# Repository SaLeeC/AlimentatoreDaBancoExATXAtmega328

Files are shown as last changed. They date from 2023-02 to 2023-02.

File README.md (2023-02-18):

# PowerSupplyFromATXPowerUnit

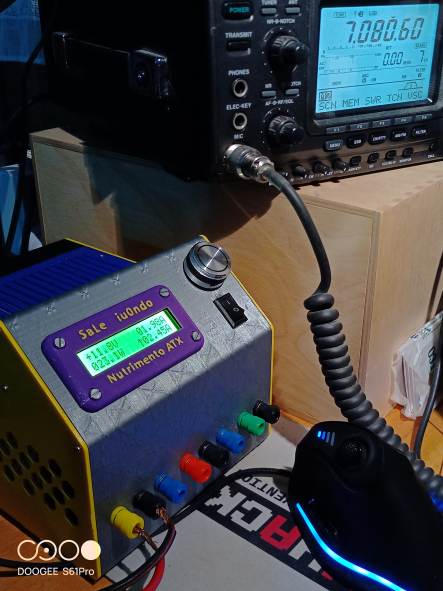
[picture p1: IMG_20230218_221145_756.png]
Immagine

          
Desk power supply made using an ATX power module salvaged from an old computer.

Alimentatore da banco realizzato utilizzando un modulo di alimentazione ATX recuperato da un vecchio computer.

# Firmware
The firmware was developed with PlatformIO.
A modified version of the library developed by Adafruit was used to interface the INA219 chip.
library update request to its developer is in progress.
At the moment, to compile without errors, you must do the following:
1) Copy the project folder to your computer
2) open the "lib\Adafruit INA219-CopiaDiSecurità" folder inside the project folder and copy its contents
3) open the ".pio\libdeps\uno\Adafruit INA219" folder and paste the copied files into it, authorizing the replacement of all files
This sequence does NOT affect other projects in your folders.
Until you upgrade the libraries this sequence will no longer be needed. 

Il firmware è stato con sviluppato con PlatformIO.
Per l'interfacciamento del chip INA219 è stata utilizzata una versione modificata della libreria sviluppata da Adafruit.
è in corso la richiesta di aggiornamento della libreria al suo sviluppatore.
Al momneto per eseguire la compilazione senza errori si deve effettuare le seguenti operazioni:
1) Copiare la cartella di progetto sul vostro computer
2) aprire la cartella "lib\Adafruit INA219-CopiaDiSicurezza" all'interno della cartella di progetto e copiarne il contenuto
3) aprire la cartella ".pio\libdeps\uno\Adafruit INA219" e incollarvi dentro i file copiati autorizzando la sostituzione di tutti i file
Questa sequenza NON influenza gli altri progetti presenti nelle vostre cartelle.
Fino a quando non eseguirete l'aggiornamento delle librerie questa sequenza non sarà più necessaria.

# Box
https://grabcad.com/library/box-for-atx-power-supply-ex-pc-1

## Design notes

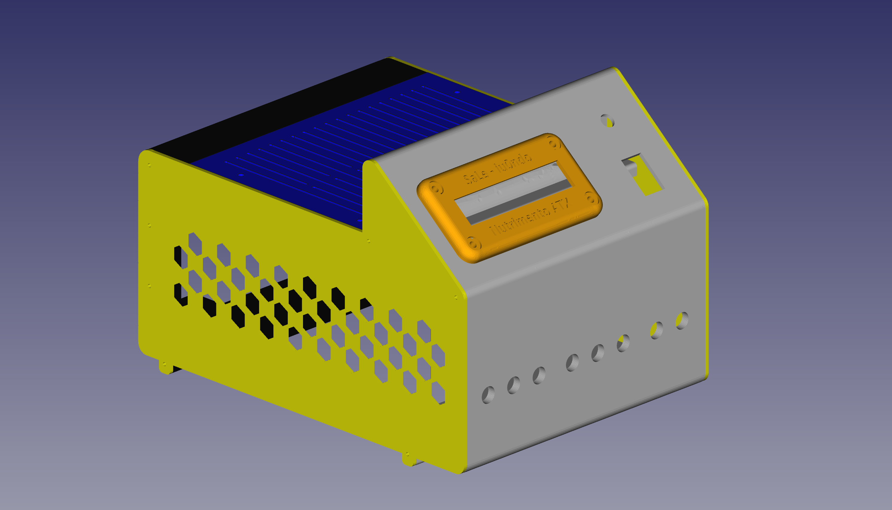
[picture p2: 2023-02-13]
Box/PowerSupplyATX-Vista.png

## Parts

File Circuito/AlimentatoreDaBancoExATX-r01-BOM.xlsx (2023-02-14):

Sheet: AlimentatoreDaBancoExATX-r01 ki
Column2 | Column3 | Column4 | Column6
 | Reference(s) | Value | Footprint
 | BZ1 | Buzzer | 12x9.5RM7.6
 | C1 | C | 1206_3216Metric
 | C2 | 1uF | 1206_3216Metric
 | C3 | 1uF | 1206_3216Metric
 | C4 | 22pF | 1206_3216Metric
 | C5 | 22pF | 1206_3216Metric
 | C6 | 1uF | 1206_3216Metric
 | C7 | 100nF | 1206_3216Metric
 | C8 | 100nF | 1206_3216Metric
 | C9 | 100nF | 1206_3216Metric
 | C10 | 100nF | 1206_3216Metric
 | C11 | 100nF | 1206_3216Metric
 | C12 | 100nF | 1206_3216Metric
 | C13 | 1uF | 1206_3216Metric
 | C14 | 100nF | 1206_3216Metric
 | C15 | 100nF | 1206_3216Metric
 | C16 | 100nF | 1206_3216Metric
 | Encoder-Switch1 | GND A B S1 V+
 | L1 | 20uH | 1206_3216Metric
 | L2 | 20uH | 1206_3216Metric
 | L3 | 20uH | 1206_3216Metric
 | L4 | 20uH | 1206_3216Metric
 | L5 | 20uH | 1206_3216Metric
 | Q1 | IRLML0030 | Package_TO_SOT_SMD:SOT-23
 | R1 | 4,7K | 1206_3216Metric
 | R2 | 4,7K | 1206_3216Metric
 | R3 | 4,7K | 1206_3216Metric
 | R4 | 100 | 1206_3216Metric
 | R5 | 1M | 1206_3216Metric
 | R6 | 10K | 1206_3216Metric
 | R7 | 10 | 1206_3216Metric
 | R8 | 10 | 1206_3216Metric
 | R9 | 10 | 1206_3216Metric
 | R10 | 10 | 1206_3216Metric
 | R11 | 10 | 1206_3216Metric
 | R12 | 10 | 1206_3216Metric
 | R13 | 10 | 1206_3216Metric
 | R14 | 10 | 1206_3216Metric
 | R15 | 10 | 1206_3216Metric
 | R16 | 10 | 1206_3216Metric
 | R18 | 0,1 | 2512_6332Metric
 | R20 | 0.1 | 2512_6332Metric
 | Reset1 | SW_Push | 6mm
 | RV1 | 10K
 | U2 | PCF8574 | SOIC-16W_7.5x10.3mm_P1.27mm
 | U3 | ATmega328-PU | DIP-28_W7.62mm
 | U4 | INA219AxD | SOIC-8_3.9x4.9mm_P1.27mm
 | U6-0x41 | INA219AxD | SOIC-8_3.9x4.9mm_P1.27mm
 | U8-0x40 | INA219AxD | SOIC-8_3.9x4.9mm_P1.27mm
 | Y1 | 16MHz
Qty | Reference(s) | Value | Footprint
1 | BZ1 | Buzzer | 12x9.5RM7.6
1 | C1 | C | 1206_3216Metric
4 | C2, C3, C6, C13 | 1uF | 1206_3216Metric
2 | C4, C5 | 22pF | 1206_3216Metric
9 | C7, C8, C9, C10, C11, C12, C14, C15, C16 | 100nF | 1206_3216Metric
1 | Encoder-Switch1 | GND A B S1 V+
4 | L1, L2, L3, L4, L5 | 20uH | 1206_3216Metric
1 | Q1 | IRLML0030 | Package_TO_SOT_SMD:SOT-23
3 | R1, R2, R3 | 4,7K | 1206_3216Metric
1 | R4 | 100 | 1206_3216Metric
1 | R5 | 1M | 1206_3216Metric
1 | R6 | 10K | 1206_3216Metric
10 | R7, R8, R9, R10, R11, R12, R13, R14, R15, R16 | 10 | 1206_3216Metric
1 | R18 | 0,1 | 2512_6332Metric
1 | R20 | 0.1 | 2512_6332Metric
1 | Reset1 | SW_Push | 6mm
1 | RV1 | 10K
1 | U2 | PCF8574 | SOIC-16W_7.5x10.3mm_P1.27mm
1 | U3 | ATmega328-PU | DIP-28_W7.62mm
3 | U4, U6-0x41, U8-0x40 | INA219AxD | SOIC-8_3.9x4.9mm_P1.27mm
1 | Y1 | 16MHz

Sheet: AlimentatoreDaBancoExATX-r01.ki
Source:,"I:\OneDrive\Progetti Integrati\AlimentatoreDaBancoExATX\Kc\AlimentatoreDaBancoExATX-r01\AlimentatoreDaBancoExATX-r01.kicad_pro\AlimentatoreDaBancoExATX-r01.kicad_pro.kicad_sch"
Date:,"13/02/2023 14:37:48"
Tool:,"Eeschema (6.0.10)"
Generator:,"I:\KiCad6\bin\scripting\plugins/bom_csv_grouped_by_value.py"
Component Count:,"107"
Individual Components:
Item,"Qty","Reference(s)","Value","LibPart","Footprint","Datasheet"
,"","3.3-1","Conn_01x01_Female","Connector:Conn_01x01_Female","MountingHole:MountingHole_4.3mm_M4_Pad_Via","~"
,"","3.3-2","Conn_01x01_Female","Connector:Conn_01x01_Female","MountingHole:MountingHole_4.3x6.2mm_M4_Pad_Via","~"
,"","+5-1","Conn_01x01_Female","Connector:Conn_01x01_Female","MountingHole:MountingHole_4.3mm_M4_Pad_Via","~"
,"","+5-2","Conn_01x01_Female","Connector:Conn_01x01_Female","MountingHole:MountingHole_4.3x6.2mm_M4_Pad_Via","~"
,"","+12-1","Conn_01x01_Female","Connector:Conn_01x01_Female","MountingHole:MountingHole_4.3mm_M4_Pad_Via","~"
,"","+12-2","Conn_01x01_Female","Connector:Conn_01x01_Female","MountingHole:MountingHole_4.3x6.2mm_M4_Pad_Via","~"
,"","-5-1","Conn_01x01_Female","Connector:Conn_01x01_Female","MountingHole:MountingHole_2.7mm_Pad_Via","~"
,"","-5-2","Conn_01x01_Female","Connector:Conn_01x01_Female","MountingHole:MountingHole_4.3x6.2mm_M4_Pad_Via","~"
,"","-12-1","Conn_01x01_Female","Connector:Conn_01x01_Female","MountingHole:MountingHole_2.7mm_Pad_Via","~"
,"","-12-2","Conn_01x01_Female","Connector:Conn_01x01_Female","MountingHole:MountingHole_4.3x6.2mm_M4_Pad_Via","~"
,"","BZ1","Buzzer","Device:Buzzer","Buzzer_Beeper:Buzzer_12x9.5RM7.6","~"
,"","C1","C","Device:C","Capacitor_SMD:C_1206_3216Metric","~"
,"","C2","1uF","Device:C","Capacitor_SMD:C_1206_3216Metric","~"
,"","C3","1uF","Device:C","Capacitor_SMD:C_1206_3216Metric","~"
,"","C4","22pF","Device:C","Capacitor_SMD:C_1206_3216Metric","~"
,"","C5","22pF","Device:C","Capacitor_SMD:C_1206_3216Metric","~"
,"","C6","1uF","Device:C","Capacitor_SMD:C_1206_3216Metric","~"
,"","C7","100nF","Device:C","Capacitor_SMD:C_1206_3216Metric","~"
,"","C8","100nF","Device:C","Capacitor_SMD:C_1206_3216Metric","~"
,"","C9","100nF","Device:C","Capacitor_SMD:C_1206_3216Metric","~"
,"","C10","100nF","Device:C","Capacitor_SMD:C_1206_3216Metric","~"
,"","C11","100nF","Device:C","Capacitor_SMD:C_1206_3216Metric","~"
,"","C12","100nF","Device:C","Capacitor_SMD:C_1206_3216Metric","~"
,"","C13","1uF","Device:C","Capacitor_SMD:C_1206_3216Metric","~"
,"","C14","100nF","Device:C","Capacitor_SMD:C_1206_3216Metric","~"
,"","C15","100nF","Device:C","Capacitor_SMD:C_1206_3216Metric","~"
,"","C16","100nF","Device:C","Capacitor_SMD:C_1206_3216Metric","~"
,"","Encoder-Switch1","GND A B S1 S2 V+","Connector:Conn_01x06_Male","Connector_PinHeader_2.54mm:PinHeader_1x06_P2.54mm_Vertical","~"
,"","GND1","Conn_01x01_Female","Connector:Conn_01x01_Female","MountingHole:MountingHole_4.3mm_M4_Pad_Via","~"
,"","GND2","Conn_01x01_Female","Connector:Conn_01x01_Female","MountingHole:MountingHole_4.3mm_M4_Pad_Via","~"
,"","GND3","Conn_01x01_Female","Connector:Conn_01x01_Female","MountingHole:MountingHole_4.3mm_M4_Pad_Via","~"
,"","GND-1","Conn_01x01_Female","Connector:Conn_01x01_Female","MountingHole:MountingHole_4.3x6.2mm_M4_Pad_Via","~"
,"","GND-2","Conn_01x01_Female","Connector:Conn_01x01_Female","MountingHole:MountingHole_4.3x6.2mm_M4_Pad_Via","~"
,"","GND-3","Conn_01x01_Female","Connector:Conn_01x01_Female","MountingHole:MountingHole_4.3x6.2mm_M4_Pad_Via","~"
,"","IIC1","GND SDA SCL V+","Connector:Conn_01x04_Male","Connector_PinHeader_2.54mm:PinHeader_1x04_P2.54mm_Vertical","~"
,"","J1","ProgPort","Connector:Conn_01x04_Male","Connector_PinHeader_2.54mm:PinHeader_1x04_P2.54mm_Vertical","~"
,"","J4","LCD16X2","Connector:Conn_01x16_Female","Connector_PinSocket_2.54mm:PinSocket_1x16_P2.54mm_Vertical","~"
,"","JP1","A0","Jumper:SolderJumper_3_Open","Jumper:SolderJumper-3_P1.3mm_Open_RoundedPad1.0x1.5mm","~"
,"","JP2","A1","Jumper:SolderJumper_3_Open","Jumper:SolderJumper-3_P1.3mm_Open_RoundedPad1.0x1.5mm","~"
,"","JP3","A2","Jumper:SolderJumper_3_Open","Jumper:SolderJumper-3_P1.3mm_Open_RoundedPad1.0x1.5mm","~"
,"","JP4","4","Jumper:SolderJumper_2_Open","Jumper:SolderJumper-2_P1.3mm_Open_RoundedPad1.0x1.5mm","~"
,"","JP5","5","Jumper:SolderJumper_2_Open","Jumper:SolderJumper-2_P1.3mm_Open_RoundedPad1.0x1.5mm","~"
,"","JP6","6","Jumper:SolderJumper_2_Open","Jumper:SolderJumper-2_P1.3mm_Open_RoundedPad1.0x1.5mm","~"
,"","JP7","7","Jumper:SolderJumper_2_Open","Jumper:SolderJumper-2_P1.3mm_Open_RoundedPad1.0x1.5mm","~"
,"","JP8","8","Jumper:SolderJumper_2_Open","Jumper:SolderJumper-2_P1.3mm_Open_RoundedPad1.0x1.5mm","~"
,"","JP9","9","Jumper:SolderJumper_2_Open","Jumper:SolderJumper-2_P1.3mm_Open_RoundedPad1.0x1.5mm","~"
,"","JP10","10","Jumper:SolderJumper_2_Open","Jumper:SolderJumper-2_P1.3mm_Open_RoundedPad1.0x1.5mm","~"
,"","JP11","11","Jumper:SolderJumper_2_Open","Jumper:SolderJumper-2_P1.3mm_Open_RoundedPad1.0x1.5mm","~"
,"","JP12","Jumper_2_Open","Jumper:Jumper_2_Open","Jumper:SolderJumper-2_P1.3mm_Open_RoundedPad1.0x1.5mm","~"
,"","JP13","Jumper_2_Open","Jumper:Jumper_2_Open","Jumper:SolderJumper-2_P1.3mm_Open_RoundedPad1.0x1.5mm","~"
,"","JP14","Jumper_2_Open","Jumper:Jumper_2_Open","Jumper:SolderJumper-2_P1.3mm_Open_RoundedPad1.0x1.5mm","~"
,"","JP15","Jumper_2_Open","Jumper:Jumper_2_Open","Jumper:SolderJumper-2_P1.3mm_Open_RoundedPad1.0x1.5mm","~"
,"","JP16","Jumper_2_Open","Jumper:Jumper_2_Open","Jumper:SolderJumper-2_P1.3mm_Open_RoundedPad1.0x1.5mm","~"
,"","JP17","Jumper_2_Open","Jumper:Jumper_2_Open","Jumper:SolderJumper-2_P1.3mm_Open_RoundedPad1.0x1.5mm","~"
,"","JP18","Jumper_2_Open","Jumper:Jumper_2_Open","Jumper:SolderJumper-2_P1.3mm_Open_RoundedPad1.0x1.5mm","~"
,"","JP19","Jumper_2_Open","Jumper:Jumper_2_Open","Jumper:SolderJumper-2_P1.3mm_Open_RoundedPad1.0x1.5mm","~"
,"","JP20","Jumper_2_Open","Jumper:Jumper_2_Open","Jumper:SolderJumper-2_P1.3mm_Open_RoundedPad1.0x1.5mm","~"
,"","JP21","Jumper_2_Open","Jumper:Jumper_2_Open","Jumper:SolderJumper-2_P1.3mm_Open_RoundedPad1.0x1.5mm","~"
,"","L1","L","Device:L","Inductor_SMD:L_1206_3216Metric","~"
,"","L2","20uH","Device:L","Inductor_SMD:L_1206_3216Metric","~"
,"","L3","20uH","Device:L","Inductor_SMD:L_1206_3216Metric","~"
,"","L4","20uH","Device:L","Inductor_SMD:L_1206_3216Metric","~"
,"","L5","20uH","Device:L","Inductor_SMD:L_1206_3216Metric","~"
,"","Q1","IRLML0030","Transistor_FET:IRLML0030","Package_TO_SOT_SMD:SOT-23","https://www.infineon.com/dgdl/irlml0030pbf.pdf?fileId=5546d462533600a401535664773825df"
,"","R1","4,7K","Device:R","Resistor_SMD:R_1206_3216Metric","~"
,"","R2","4,7K","Device:R","Resistor_SMD:R_1206_3216Metric","~"
,"","R3","4,7K","Device:R","Resistor_SMD:R_1206_3216Metric","~"
,"","R4","100","Device:R","Resistor_SMD:R_1206_3216Metric","~"
,"","R5","1M","Device:R","Resistor_SMD:R_1206_3216Metric","~"
,"","R6","10K","Device:R","Resistor_SMD:R_1206_3216Metric","~"
,"","R7","10","Device:R","Resistor_SMD:R_1206_3216Metric","~"
,"","R8","10","Device:R","Resistor_SMD:R_1206_3216Metric","~"
,"","R9","10","Device:R","Resistor_SMD:R_1206_3216Metric","~"
,"","R10","10","Device:R","Resistor_SMD:R_1206_3216Metric","~"
,"","R11","10","Device:R","Resistor_SMD:R_1206_3216Metric","~"
,"","R12","10","Device:R","Resistor_SMD:R_1206_3216Metric","~"
,"","R13","10","Device:R","Resistor_SMD:R_1206_3216Metric","~"
,"","R14","10","Device:R","Resistor_SMD:R_1206_3216Metric","~"
,"","R15","10","Device:R","Resistor_SMD:R_1206_3216Metric","~"
,"","R16","10","Device:R","Resistor_SMD:R_1206_3216Metric","~"
,"","R18","0,1","Device:R","Resistor_SMD:R_2512_6332Metric","~"
,"","R20","0.1","Device:R","Resistor_SMD:R_2512_6332Metric","~"
,"","Reset1","SW_Push","Switch:SW_Push","Button_Switch_THT:SW_PUSH_6mm","~"
,"","RV1","10K","Device:R_Potentiometer_Trim","Potentiometer_THT:Potentiometer_ACP_CA9-V10_Vertical_Hole","~"
,"","RV2","10K","Device:R_Potentiometer_Trim","Potentiometer_THT:Potentiometer_ACP_CA14V-15_Vertical_Hole","~"
,"","SlowReset1","Jumper_2_Open","Jumper:Jumper_2_Open","Jumper:SolderJumper-2_P1.3mm_Open_RoundedPad1.0x1.5mm","~"
,"","TP1","SDA","Connector:TestPoint","TestPoint:TestPoint_Pad_D1.5mm","~"
,"","TP2","SCL","Connector:TestPoint","TestPoint:TestPoint_Pad_D1.5mm","~"
,"","TP3","Int","Connector:TestPoint","TestPoint:TestPoint_Pad_D1.5mm","~"
,"","TP4","I/O0","Connector:TestPoint","TestPoint:TestPoint_Pad_D1.5mm","~"
,"","TP5","I/O1","Connector:TestPoint","TestPoint:TestPoint_Pad_D1.5mm","~"
,"","TP6","I/O2","Connector:TestPoint","TestPoint:TestPoint_Pad_D1.5mm","~"
,"","TP7","I/O3","Connector:TestPoint","TestPoint:TestPoint_Pad_D1.5mm","~"
,"","TP8","I/O4","Connector:TestPoint","TestPoint:TestPoint_Pad_D1.5mm","~"
,"","TP9","I/O5","Connector:TestPoint","TestPoint:TestPoint_Pad_D1.5mm","~"
,"","TP10","I/O6","Connector:TestPoint","TestPoint:TestPoint_Pad_D1.5mm","~"
,"","TP11","I/O7","Connector:TestPoint","TestPoint:TestPoint_Pad_D1.5mm","~"
,"","TP12","-12Out","Connector:TestPoint","TestPoint:TestPoint_Pad_D1.5mm","~"
,"","TP13","-12In","Connector:TestPoint","TestPoint:TestPoint_Pad_D1.5mm","~"
,"","TP14","-5Out","Connector:TestPoint","TestPoint:TestPoint_Pad_D1.5mm","~"
,"","TP15","-5In","Connector:TestPoint","TestPoint:TestPoint_Pad_D1.5mm","~"
,"","U2","PCF8574","Interface_Expansion:PCF8574","Package_SO:SOIC-16W_7.5x10.3mm_P1.27mm","http://www.nxp.com/documents/data_sheet/PCF8574_PCF8574A.pdf"
,"","U3","ATmega328-PU","MCU_Microchip_ATmega:ATmega328-PU","Package_DIP:DIP-28_W7.62mm","http://ww1.microchip.com/downloads/en/DeviceDoc/ATmega328_P%20AVR%20MCU%20with%20picoPower%20Technology%20Data%20Sheet%2040001984A.pdf"
,"","U4","INA219AxD","Analog_ADC:INA219AxD","Package_SO:SOIC-8_3.9x4.9mm_P1.27mm","http://www.ti.com/lit/ds/symlink/ina219.pdf"
,"","U6-0x41","INA219AxD","Analog_ADC:INA219AxD","Package_SO:SOIC-8_3.9x4.9mm_P1.27mm","http://www.ti.com/lit/ds/symlink/ina219.pdf"
,"","U8-0x40","INA219AxD","Analog_ADC:INA219AxD","Package_SO:SOIC-8_3.9x4.9mm_P1.27mm","http://www.ti.com/lit/ds/symlink/ina219.pdf"
,"","Y1","16MHz","Device:Crystal","Crystal:Crystal_HC49-U_Vertical","~"
Collated Components:
Item,"Qty","Reference(s)","Value","LibPart","Footprint","Datasheet"
1,"6","3.3-1, +5-1, +12-1, GND1, GND2, GND3","Conn_01x01_Female","Connector:Conn_01x01_Female","MountingHole:MountingHole_4.3mm_M4_Pad_Via","~"
2,"8","3.3-2, +5-2, +12-2, -5-2, -12-2, GND-1, GND-2, GND-3","Conn_01x01_Female","Connector:Conn_01x01_Female","MountingHole:MountingHole_4.3x6.2mm_M4_Pad_Via","~"
3,"2","-5-1, -12-1","Conn_01x01_Female","Connector:Conn_01x01_Female","MountingHole:MountingHole_2.7mm_Pad_Via","~"
4,"1","BZ1","Buzzer","Device:Buzzer","Buzzer_Beeper:Buzzer_12x9.5RM7.6","~"
5,"1","C1","C","Device:C","Capacitor_SMD:C_1206_3216Metric","~"
6,"4","C2, C3, C6, C13","1uF","Device:C","Capacitor_SMD:C_1206_3216Metric","~"
7,"2","C4, C5","22pF","Device:C","Capacitor_SMD:C_1206_3216Metric","~"
8,"9","C7, C8, C9, C10, C11, C12, C14, C15, C16","100nF","Device:C","Capacitor_SMD:C_1206_3216Metric","~"
9,"1","Encoder-Switch1","GND A B S1 S2 V+","Connector:Conn_01x06_Male","Connector_PinHeader_2.54mm:PinHeader_1x06_P2.54mm_Vertical","~"
10,"1","IIC1","GND SDA SCL V+","Connector:Conn_01x04_Male","Connector_PinHeader_2.54mm:PinHeader_1x04_P2.54mm_Vertical","~"
11,"1","J1","ProgPort","Connector:Conn_01x04_Male","Connector_PinHeader_2.54mm:PinHeader_1x04_P2.54mm_Vertical","~"
12,"1","J4","LCD16X2","Connector:Conn_01x16_Female","Connector_PinSocket_2.54mm:PinSocket_1x16_P2.54mm_Vertical","~"
13,"1","JP1","A0","Jumper:SolderJumper_3_Open","Jumper:SolderJumper-3_P1.3mm_Open_RoundedPad1.0x1.5mm","~"
14,"1","JP2","A1","Jumper:SolderJumper_3_Open","Jumper:SolderJumper-3_P1.3mm_Open_RoundedPad1.0x1.5mm","~"
15,"1","JP3","A2","Jumper:SolderJumper_3_Open","Jumper:SolderJumper-3_P1.3mm_Open_RoundedPad1.0x1.5mm","~"
16,"1","JP4","4","Jumper:SolderJumper_2_Open","Jumper:SolderJumper-2_P1.3mm_Open_RoundedPad1.0x1.5mm","~"
17,"1","JP5","5","Jumper:SolderJumper_2_Open","Jumper:SolderJumper-2_P1.3mm_Open_RoundedPad1.0x1.5mm","~"
18,"1","JP6","6","Jumper:SolderJumper_2_Open","Jumper:SolderJumper-2_P1.3mm_Open_RoundedPad1.0x1.5mm","~"
19,"1","JP7","7","Jumper:SolderJumper_2_Open","Jumper:SolderJumper-2_P1.3mm_Open_RoundedPad1.0x1.5mm","~"
20,"1","JP8","8","Jumper:SolderJumper_2_Open","Jumper:SolderJumper-2_P1.3mm_Open_RoundedPad1.0x1.5mm","~"
21,"1","JP9","9","Jumper:SolderJumper_2_Open","Jumper:SolderJumper-2_P1.3mm_Open_RoundedPad1.0x1.5mm","~"
22,"1","JP10","10","Jumper:SolderJumper_2_Open","Jumper:SolderJumper-2_P1.3mm_Open_RoundedPad1.0x1.5mm","~"
23,"1","JP11","11","Jumper:SolderJumper_2_Open","Jumper:SolderJumper-2_P1.3mm_Open_RoundedPad1.0x1.5mm","~"
24,"11","JP12, JP13, JP14, JP15, JP16, JP17, JP18, JP19, JP20, JP21, SlowReset1","Jumper_2_Open","Jumper:Jumper_2_Open","Jumper:SolderJumper-2_P1.3mm_Open_RoundedPad1.0x1.5mm","~"
25,"1","L1","L","Device:L","Inductor_SMD:L_1206_3216Metric","~"
26,"4","L2, L3, L4, L5","20uH","Device:L","Inductor_SMD:L_1206_3216Metric","~"
27,"1","Q1","IRLML0030","Transistor_FET:IRLML0030","Package_TO_SOT_SMD:SOT-23","https://www.infineon.com/dgdl/irlml0030pbf.pdf?fileId=5546d462533600a401535664773825df"
28,"3","R1, R2, R3","4,7K","Device:R","Resistor_SMD:R_1206_3216Metric","~"
29,"1","R4","100","Device:R","Resistor_SMD:R_1206_3216Metric","~"
30,"1","R5","1M","Device:R","Resistor_SMD:R_1206_3216Metric","~"
31,"1","R6","10K","Device:R","Resistor_SMD:R_1206_3216Metric","~"
32,"10","R7, R8, R9, R10, R11, R12, R13, R14, R15, R16","10","Device:R","Resistor_SMD:R_1206_3216Metric","~"
33,"1","R18","0,1","Device:R","Resistor_SMD:R_2512_6332Metric","~"
34,"1","R20","0.1","Device:R","Resistor_SMD:R_2512_6332Metric","~"
35,"1","Reset1","SW_Push","Switch:SW_Push","Button_Switch_THT:SW_PUSH_6mm","~"
36,"1","RV1","10K","Device:R_Potentiometer_Trim","Potentiometer_THT:Potentiometer_ACP_CA9-V10_Vertical_Hole","~"
37,"1","RV2","10K","Device:R_Potentiometer_Trim","Potentiometer_THT:Potentiometer_ACP_CA14V-15_Vertical_Hole","~"
38,"1","TP1","SDA","Connector:TestPoint","TestPoint:TestPoint_Pad_D1.5mm","~"
39,"1","TP2","SCL","Connector:TestPoint","TestPoint:TestPoint_Pad_D1.5mm","~"
40,"1","TP3","Int","Connector:TestPoint","TestPoint:TestPoint_Pad_D1.5mm","~"
41,"1","TP4","I/O0","Connector:TestPoint","TestPoint:TestPoint_Pad_D1.5mm","~"
42,"1","TP5","I/O1","Connector:TestPoint","TestPoint:TestPoint_Pad_D1.5mm","~"
43,"1","TP6","I/O2","Connector:TestPoint","TestPoint:TestPoint_Pad_D1.5mm","~"
44,"1","TP7","I/O3","Connector:TestPoint","TestPoint:TestPoint_Pad_D1.5mm","~"
45,"1","TP8","I/O4","Connector:TestPoint","TestPoint:TestPoint_Pad_D1.5mm","~"
46,"1","TP9","I/O5","Connector:TestPoint","TestPoint:TestPoint_Pad_D1.5mm","~"
47,"1","TP10","I/O6","Connector:TestPoint","TestPoint:TestPoint_Pad_D1.5mm","~"
48,"1","TP11","I/O7","Connector:TestPoint","TestPoint:TestPoint_Pad_D1.5mm","~"
49,"1","TP12","-12Out","Connector:TestPoint","TestPoint:TestPoint_Pad_D1.5mm","~"
50,"1","TP13","-12In","Connector:TestPoint","TestPoint:TestPoint_Pad_D1.5mm","~"
51,"1","TP14","-5Out","Connector:TestPoint","TestPoint:TestPoint_Pad_D1.5mm","~"
52,"1","TP15","-5In","Connector:TestPoint","TestPoint:TestPoint_Pad_D1.5mm","~"
53,"1","U2","PCF8574","Interface_Expansion:PCF8574","Package_SO:SOIC-16W_7.5x10.3mm_P1.27mm","http://www.nxp.com/documents/data_sheet/PCF8574_PCF8574A.pdf"
54,"1","U3","ATmega328-PU","MCU_Microchip_ATmega:ATmega328-PU","Package_DIP:DIP-28_W7.62mm","http://ww1.microchip.com/downloads/en/DeviceDoc/ATmega328_P%20AVR%20MCU%20with%20picoPower%20Technology%20Data%20Sheet%2040001984A.pdf"
55,"3","U4, U6-0x41, U8-0x40","INA219AxD","Analog_ADC:INA219AxD","Package_SO:SOIC-8_3.9x4.9mm_P1.27mm","http://www.ti.com/lit/ds/symlink/ina219.pdf"
56,"1","Y1","16MHz","Device:Crystal","Crystal:Crystal_HC49-U_Vertical","~"

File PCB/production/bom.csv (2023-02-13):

Designator | Footprint | Quantity | Value | LCSC Part #
+12-1, +5-1, 3.3-1, GND1, GND2, GND3 | MountingHole_4.3mm_M4_Pad_Via | 6 | Conn_01x01_Female
+12-2, +5-2, -12-2, -5-2, 3.3-2, GND-1, GND-2, GND-3 | MountingHole_4.3x6.2mm_M4_Pad_Via | 8 | Conn_01x01_Female
-12-1, -5-1 | MountingHole_2.7mm_Pad_Via | 2 | Conn_01x01_Female
BZ1 | Buzzer_12x9.5RM7.6 | 1 | Buzzer
C1 | C_1206_3216Metric | 1 | C
C10, C11, C12, C14, C15, C16, C7, C8, C9 | C_1206_3216Metric | 9 | 100nF
C13, C2, C3, C6 | C_1206_3216Metric | 4 | 1uF
C4, C5 | C_1206_3216Metric | 2 | 22pF
Encoder-Switch1 | PinHeader_1x06_P2.54mm_Vertical | 1 | GND A B S1 S2 V+
IIC1 | PinHeader_1x04_P2.54mm_Vertical | 1 | GND SDA SCL V+
J1 | PinHeader_1x04_P2.54mm_Vertical | 1 | ProgPort
J4 | PinSocket_1x16_P2.54mm_Vertical | 1 | LCD16X2
JP1 | SolderJumper-3_P1.3mm_Open_RoundedPad1.0x1.5mm | 1 | A0
JP10 | SolderJumper-2_P1.3mm_Open_RoundedPad1.0x1.5mm | 1 | 10
JP11 | SolderJumper-2_P1.3mm_Open_RoundedPad1.0x1.5mm | 1 | 11
JP12, JP13, JP14, JP15, JP16, JP17, JP18, JP19, JP20, JP21, SlowReset1 | SolderJumper-2_P1.3mm_Open_RoundedPad1.0x1.5mm | 11 | Jumper_2_Open
JP2 | SolderJumper-3_P1.3mm_Open_RoundedPad1.0x1.5mm | 1 | A1
JP3 | SolderJumper-3_P1.3mm_Open_RoundedPad1.0x1.5mm | 1 | A2
JP4 | SolderJumper-2_P1.3mm_Open_RoundedPad1.0x1.5mm | 1 | 4
JP5 | SolderJumper-2_P1.3mm_Open_RoundedPad1.0x1.5mm | 1 | 5
JP6 | SolderJumper-2_P1.3mm_Open_RoundedPad1.0x1.5mm | 1 | 6
JP7 | SolderJumper-2_P1.3mm_Open_RoundedPad1.0x1.5mm | 1 | 7
JP8 | SolderJumper-2_P1.3mm_Open_RoundedPad1.0x1.5mm | 1 | 8
JP9 | SolderJumper-2_P1.3mm_Open_RoundedPad1.0x1.5mm | 1 | 9
L1, L2, L3, L4, L5 | L_1206_3216Metric | 5 | 20uH
Q1 | SOT-23 | 1 | IRLML0030
QRcode | AlimentatoreDaBancoExATXAtmega328 | 1 | https://github.com/SaLeeC/AlimentatoreDaBancoExATXAtmega328
R1, R2, R3 | R_1206_3216Metric | 3 | 4,7K
R10, R11, R12, R13, R14, R15, R16, R7, R8, R9 | R_1206_3216Metric | 10 | 10
R18 | R_2512_6332Metric | 1 | 0,1
R20 | R_2512_6332Metric | 1 | 0.1
R4 | R_1206_3216Metric | 1 | 100
R5 | R_1206_3216Metric | 1 | 1M
R6 | R_1206_3216Metric | 1 | 10K
RV1 | Potentiometer_ACP_CA9-V10_Vertical_Hole | 1 | 10K
RV2 | Potentiometer_ACP_CA14V-15_Vertical_Hole | 1 | 10K
Reset1 | SW_PUSH_6mm | 1 | SW_Push
TP1 | TestPoint_Pad_D1.5mm | 1 | SDA
TP10 | TestPoint_Pad_D1.5mm | 1 | I/O6
TP11 | TestPoint_Pad_D1.5mm | 1 | I/O7
TP12 | TestPoint_Pad_D1.5mm | 1 | -12Out
TP13 | TestPoint_Pad_D1.5mm | 1 | -12In
TP14 | TestPoint_Pad_D1.5mm | 1 | -5Out
TP15 | TestPoint_Pad_D1.5mm | 1 | -5In
TP2 | TestPoint_Pad_D1.5mm | 1 | SCL
TP3 | TestPoint_Pad_D1.5mm | 1 | Int
TP4 | TestPoint_Pad_D1.5mm | 1 | I/O0
TP5 | TestPoint_Pad_D1.5mm | 1 | I/O1
TP6 | TestPoint_Pad_D1.5mm | 1 | I/O2
TP7 | TestPoint_Pad_D1.5mm | 1 | I/O3
TP8 | TestPoint_Pad_D1.5mm | 1 | I/O4
TP9 | TestPoint_Pad_D1.5mm | 1 | I/O5
U2 | SOIC-16W_7.5x10.3mm_P1.27mm | 1 | PCF8574
U3 | DIP-28_W7.62mm | 1 | ATmega328-PU
U4, U6-0x41, U8-0x40 | SOIC-8_3.9x4.9mm_P1.27mm | 3 | INA219AxD
Y1 | Crystal_HC49-U_Vertical | 1 | 16MHz

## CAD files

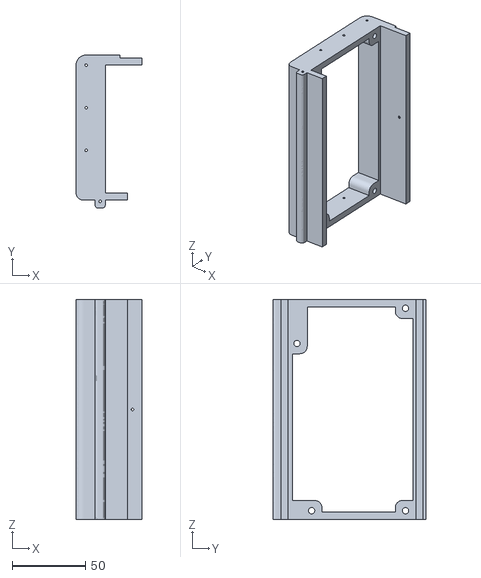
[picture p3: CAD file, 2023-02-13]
Box/AlimentatoreExPC-Profilo Posteriore ATX.stl
45.0 x 104.4 x 150.0

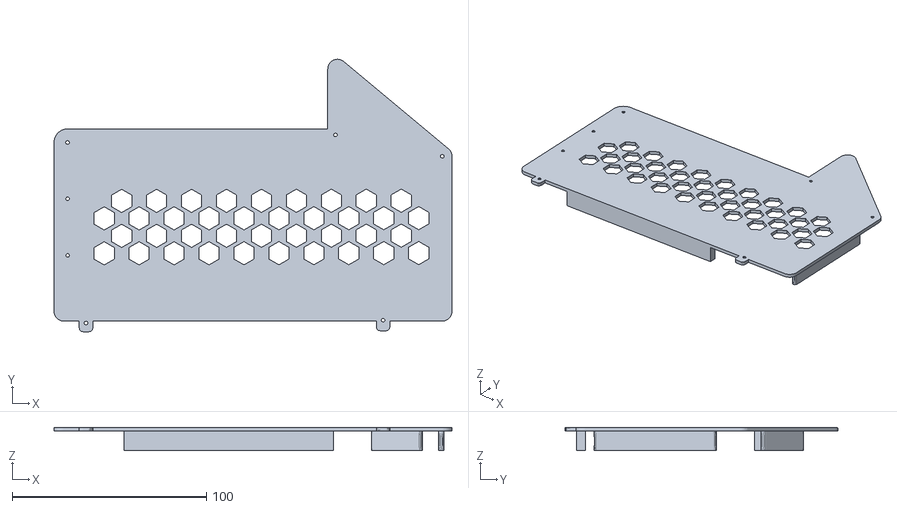
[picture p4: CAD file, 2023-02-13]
Box/AlimentatoreExPC-Pannello Laterale SX.stl
205.0 x 140.4 x 12.0

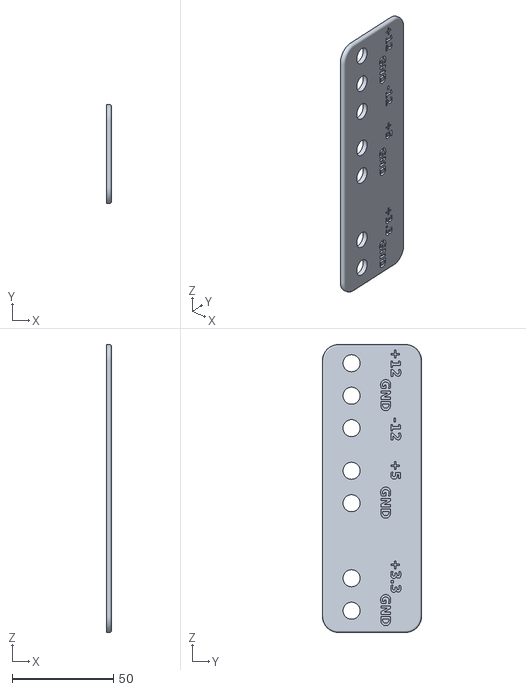
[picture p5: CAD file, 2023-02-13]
Box/AlimentatoreExPC-Placca Morsetti.stl
2.50 x 48.9 x 142.0

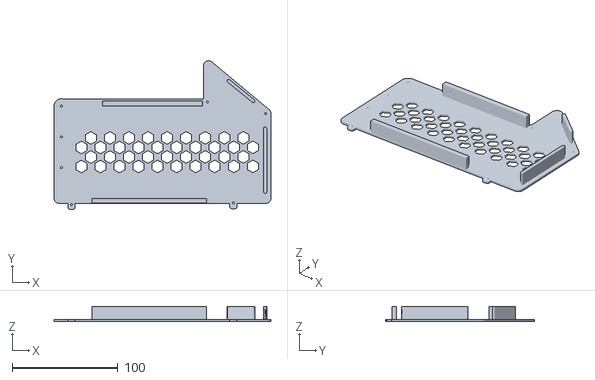
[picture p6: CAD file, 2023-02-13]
Box/AlimentatoreExPC-Pannello Laterale DX.stl
205.0 x 140.4 x 14.0

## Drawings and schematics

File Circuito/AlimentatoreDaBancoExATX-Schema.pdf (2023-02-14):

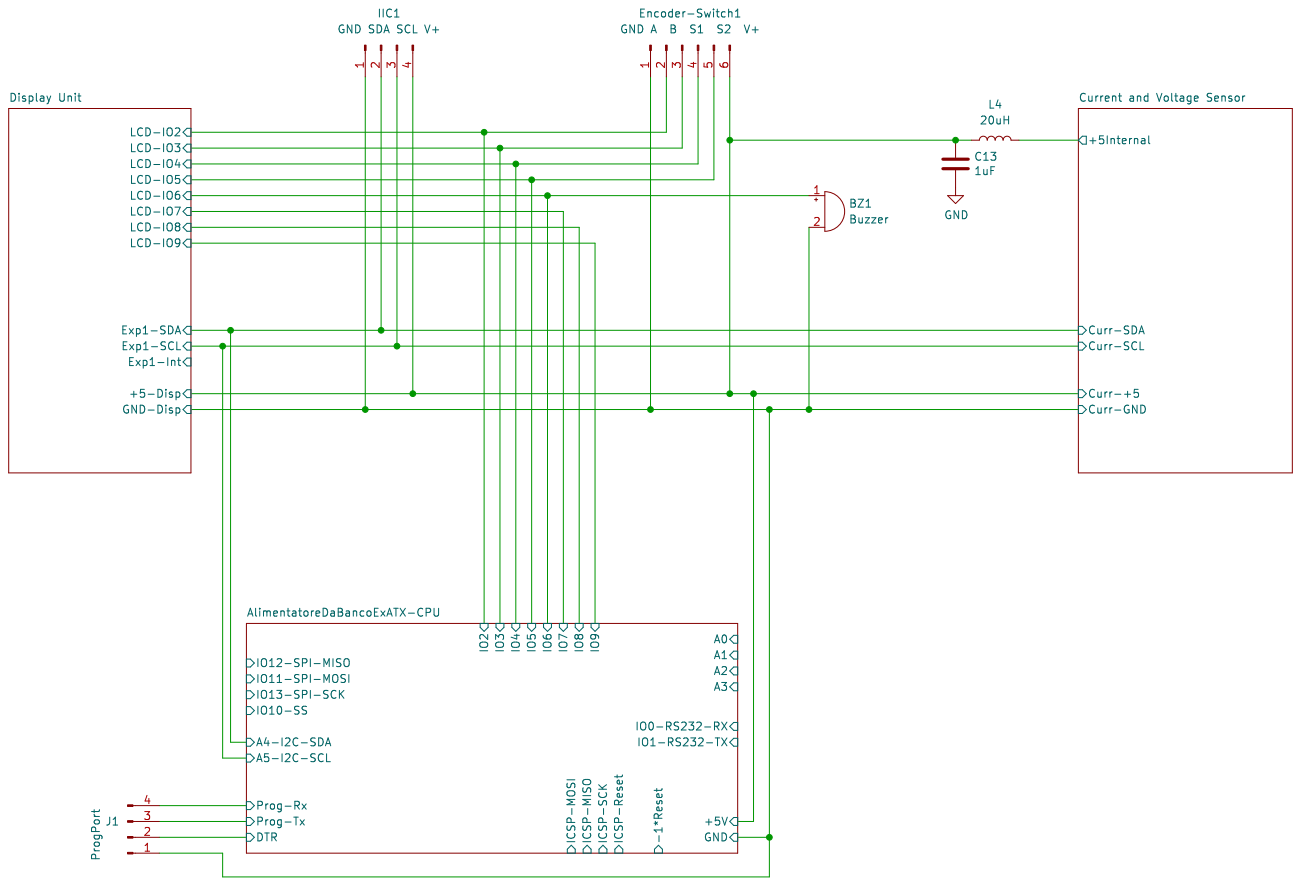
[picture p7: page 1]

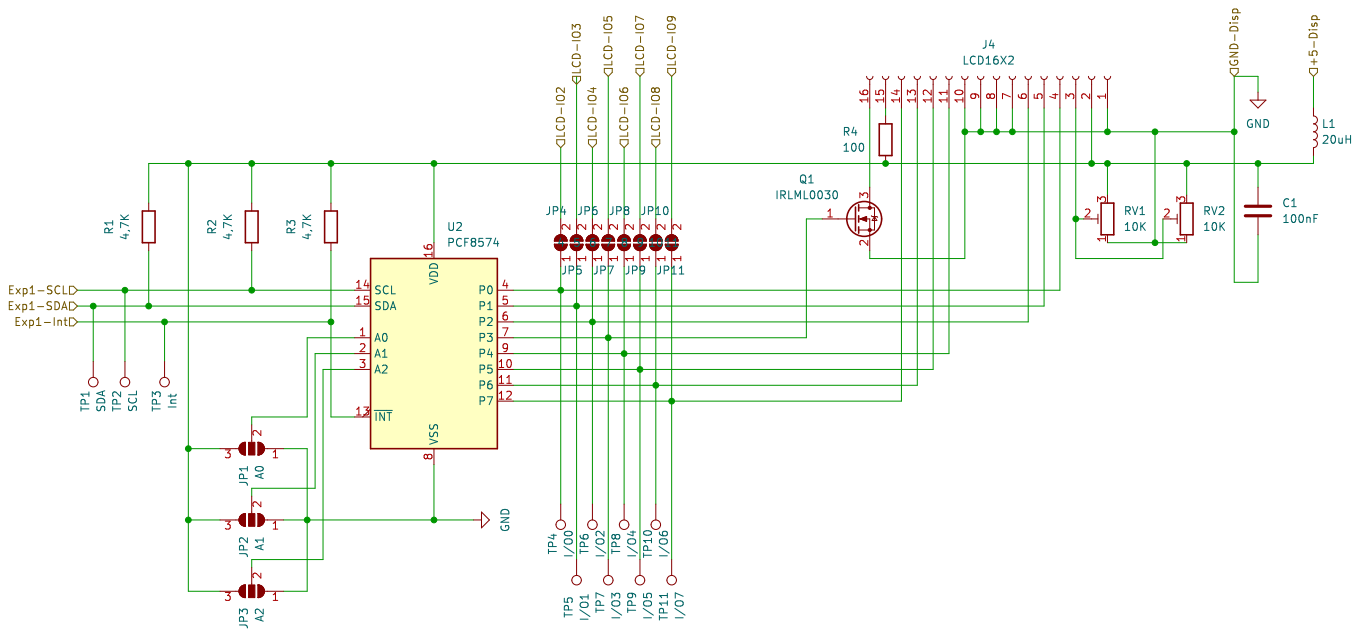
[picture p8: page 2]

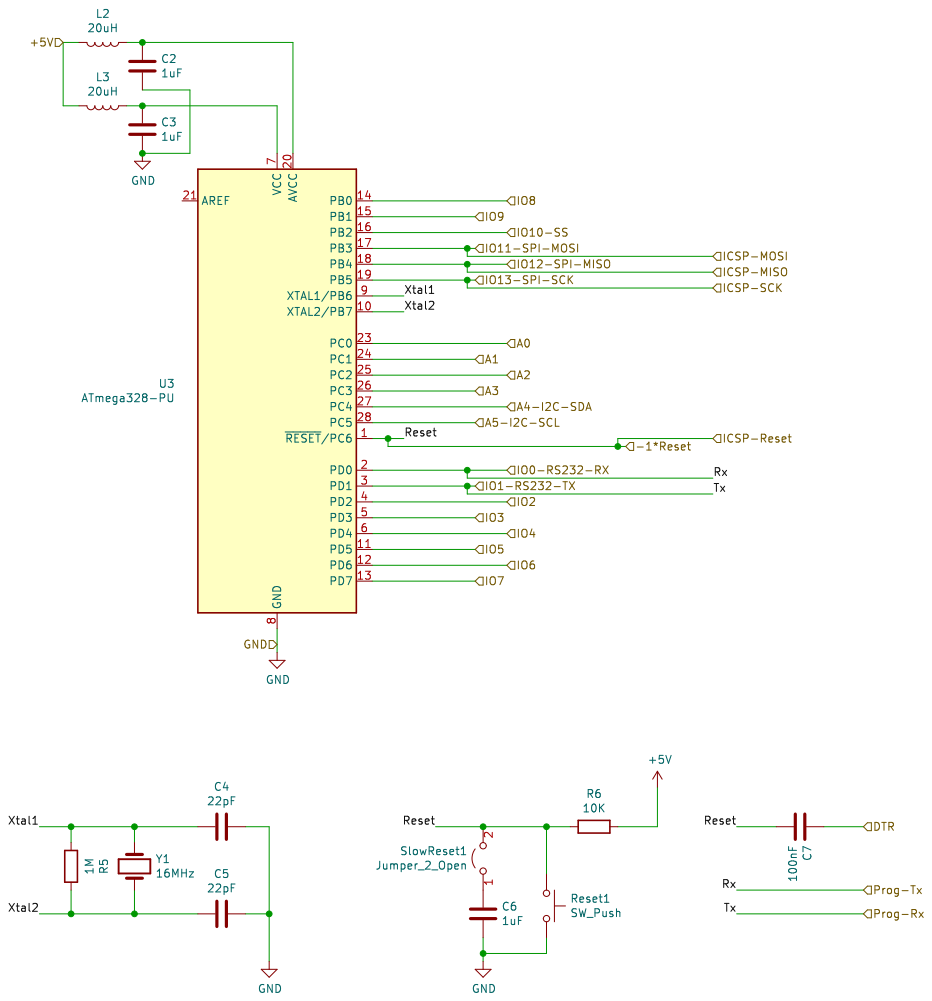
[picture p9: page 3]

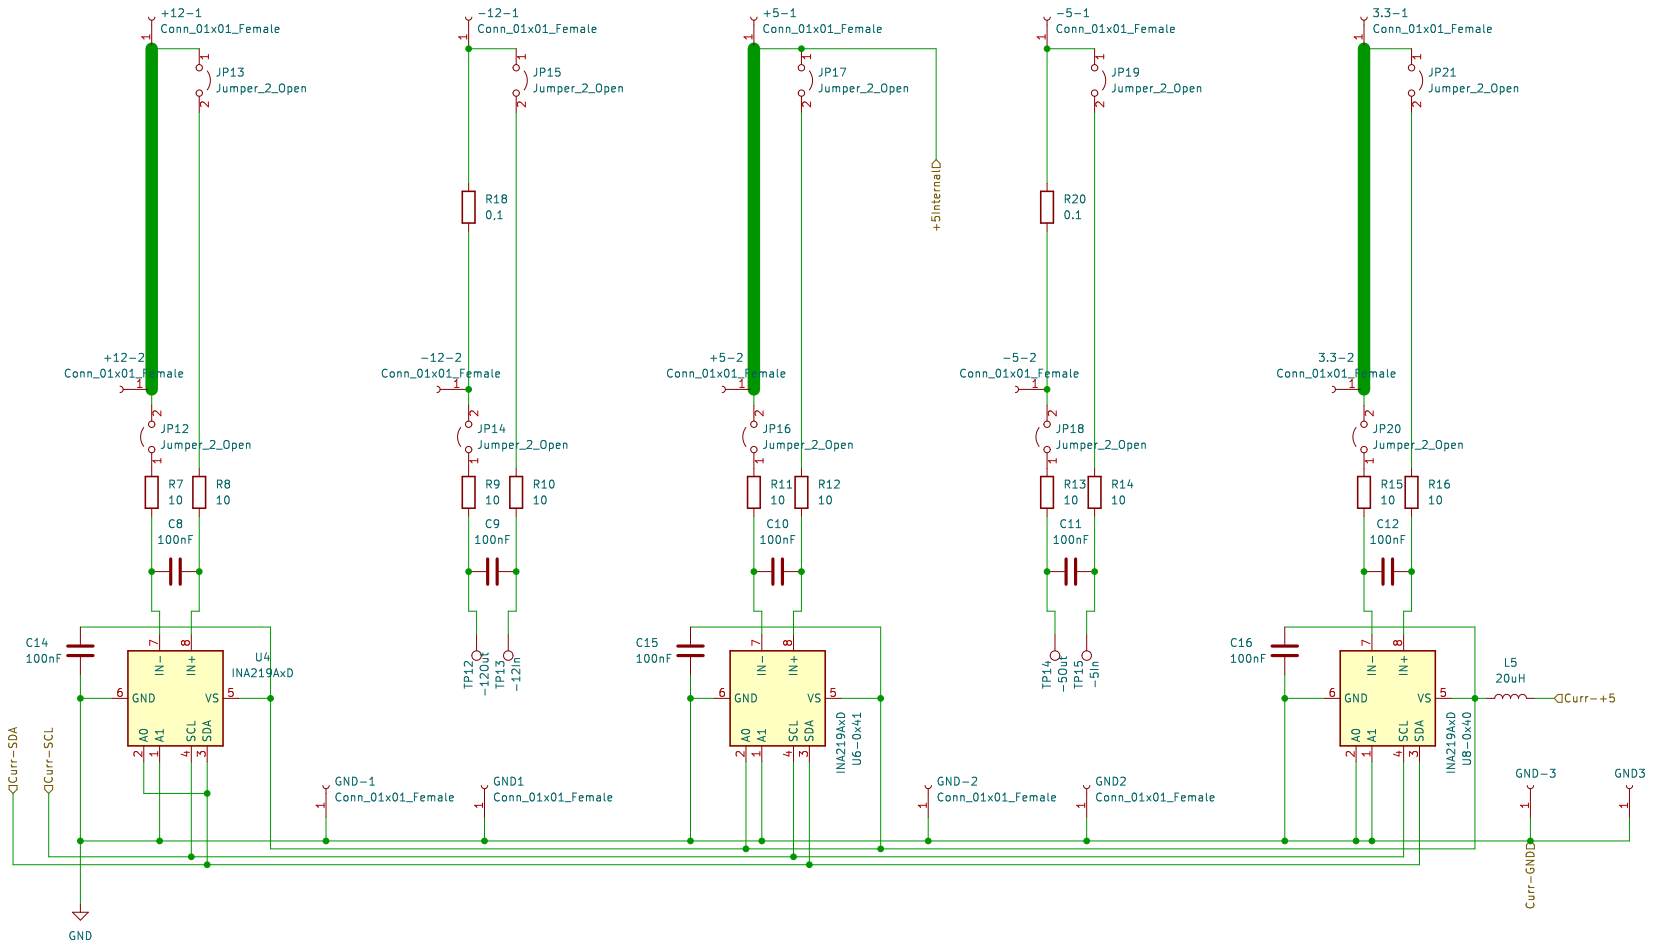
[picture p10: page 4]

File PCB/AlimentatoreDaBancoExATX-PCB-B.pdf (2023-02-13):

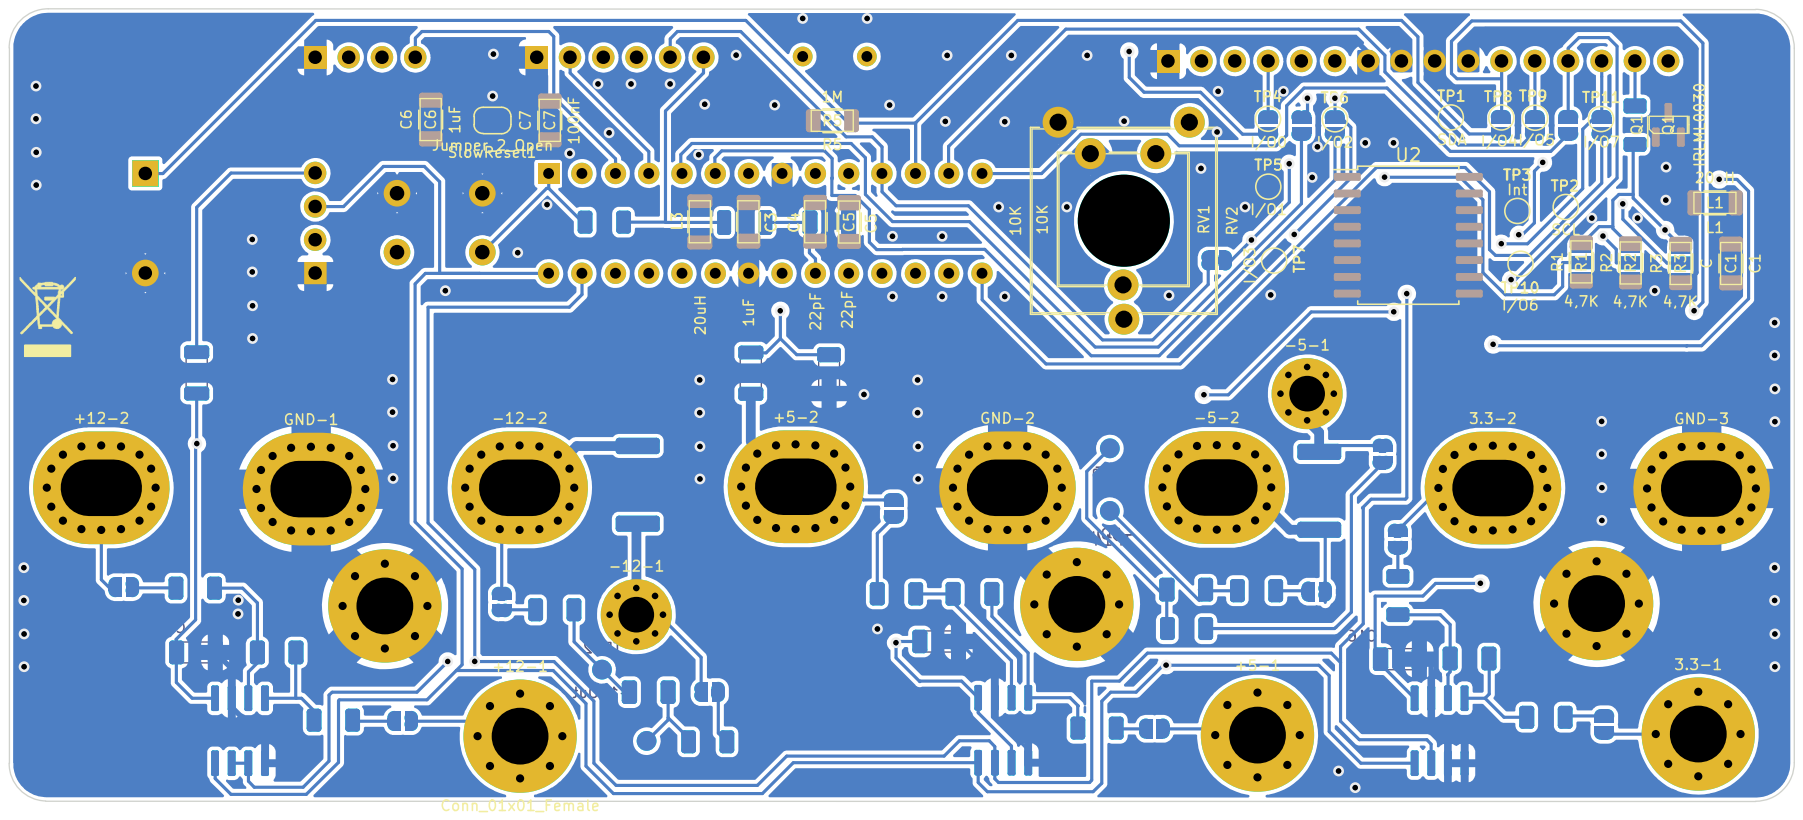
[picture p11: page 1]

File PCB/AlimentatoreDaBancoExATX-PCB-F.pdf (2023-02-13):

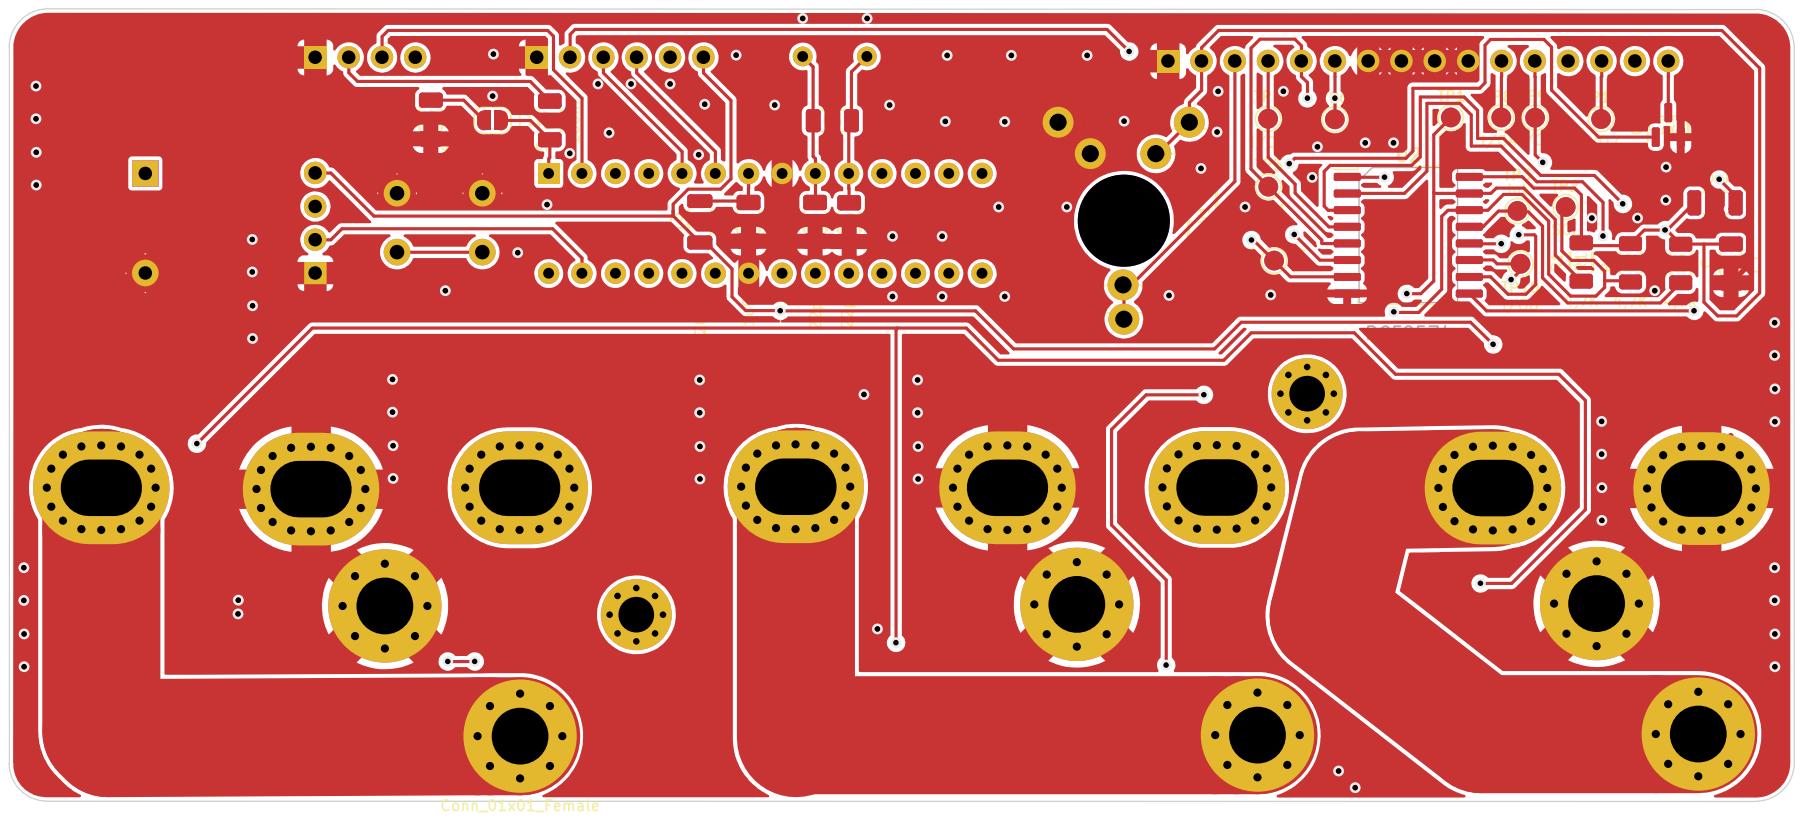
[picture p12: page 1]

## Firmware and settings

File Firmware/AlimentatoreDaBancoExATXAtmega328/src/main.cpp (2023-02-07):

#include <Arduino.h>

//Caricamenti necessari per poter realizzare il reset via software
//(utilizzato quando è stata effettuata una calibrazione)
#include <avr/io.h>
#include <avr/wdt.h>
#define Reset_AVR() wdt_enable(WDTO_30MS); while(1) {}

#include <Wire.h>
#include <EEPROM.h>
#include <RotaryEncoder.h>
#include <LiquidCrystal_I2C.h>
#include <Adafruit_INA219.h>

#include <Constant.h>
#include <Var.h>
#include <Sub.h>

//Serve solo in fase di messa a punto e di diagnostica
//per verificare la presenza dei dispositivi IIC operativi sul bus
#include <IICScanner.cpp>

// Setup a RotaryEncoder with 2 steps per latch for the 2 signal input pins:
//RotaryEncoder encoder(PIN_IN1, PIN_IN2, RotaryEncoder::LatchMode::TWO03);

// A pointer to the dynamic created rotary encoder instance.
// This will be done in setup()
RotaryEncoder *encoder = nullptr;


#include <EncoderManagement.cpp>

// This interrupt routine will be called on any change of one of the input signals
void checkPosition()
{
  encoder->tick(); // just call tick() to check the state.
}




// set the LCD address to LCDAddress for a 16 chars and 2 line display
LiquidCrystal_I2C lcd(PCF8574_ADDR_A20_A10_A00, RS, RW, En, BackLite, D4, D5, D6, D7, POSITIVE);

#include <LCDManagement.cpp>

//Crea le istanze per i misuratori di tensione e corrente
Adafruit_INA219 INA219[NumINA219] = {{Adafruit_INA219(ina219Address[0])},
                                     {Adafruit_INA219(ina219Address[1])},
                                     {Adafruit_INA219(ina219Address[2])}};

#include <INA219Management.cpp>

#include <CalibrationManagement.cpp>

void setup() 
{
  Serial.begin(115200);//Utilizzata solo in fase di messa a punto e test

  LCDSetup();//Inizializza il display LCD

  LCDWelcomeMsg();//Presenta il messaggio di accensione

//Inizializza le istanze dei sensori tensione/corrente
  for (uint8_t ii=0; ii < NumINA219; ii++)
  {
    INA219[ii].begin();
    INA219[ii].setCalibration_vvV_aaA(RShunt[ii], VOut[0],
                                      CurrentMAX[ii], CurrentLSB[ii],
                                      VoltMAX[ii],
                                      INA219_CONFIG_BADCRES_12BIT,
                                      INA219_CONFIG_BADCRES_12BIT_16S_8510US);
  }

//Inizializza il TIMER1 in maniera che generi le chiamate per l'effetuazione delle letture 
//del campo (tensione, corrente e potenza) e il ciclo di aggiornamento del display LCD
/*Calculations : 
  System clock 16 Mhz and Prescalar 8 (CS12 0, CS11 1, CS10 0);
  Timer 1 speed = 16000khz/1   = 16000.0 Khz    
  Pulse time = 1/16000 Khz =  0.0625us  
  Count up to =  2500us /  0.0625us = 40000 (so this is the value the OCR register should have)
*/
  cli();//stop interrupts

//set timer1 interrupt at 10mS (100 campioni al secondo)
  TCCR1A = 0;// Reset entire TCCR1A to 0
  TCCR1B = 0;// Reset entire TCCR1B to 0

  TCCR1B |= (1 << CS02) | (0 << CS01) | (0 << CS00);   
  // enable timer compare interrupt
  TIMSK1 |= B00000010;
  OCR1A = 620;//Finally we set compare register A to this value  
  sei();//Enable back the interrupts
  

  pinMode(8, OUTPUT);//riferisce sullo stato di lettura dei sensori tensione/corrente
  pinMode(9, OUTPUT);//riferisce sullo stato del ciclo di aggiornamento del display LCD
  pinMode(EncoderSwitch, INPUT);//Pulsante dell'encoder
  pinMode(DebugOn, INPUT_PULLUP);


  // use TWO03 mode when PIN_IN1, PIN_IN2 signals are both LOW or HIGH in latch position.
  encoder = new RotaryEncoder(PIN_IN1, PIN_IN2, RotaryEncoder::LatchMode::TWO03);

  // register interrupt routine
  attachInterrupt(digitalPinToInterrupt(PIN_IN1), checkPosition, CHANGE);
  attachInterrupt(digitalPinToInterrupt(PIN_IN2), checkPosition, CHANGE);


//Test dei device IIC. Da attivare in fase di test
//  IICScann();

  //Se il pulsante è premuto in fase di accensione, al rilascio va a fare la calibrazione
  if (digitalRead(EncoderSwitch)==0)
  {
    lcd.clear();
    lcd.print(" Rilasciare per ");
    lcd.setCursor(0,1);
    lcd.print("    iniziare    ");
    while(digitalRead(EncoderSwitch)==0)
    {
    }
    Calibrate();
  }

  //Carica i valori di calibrazione nelle variabili di servizio
  ReadCalibration();

  //Informa sullo stato dello switch che attiva il Debug
  Serial.println("Debug Attivo");
}

//Reagisce alla chiamata dell'interrupt generato dal TIMER1, setta la
//variabile di servizio e azzera il TIMER per il prossimo ciclo
ISR(TIMER1_COMPA_vect)
{
  TCNT1  = 0;
  Timer1Flag=1;
  TCNT1  = 0;
}

void loop() 
{
int EncoderAppo; 

  if(UpDisplay==25)
  {
    LCDShowValue();//Presenta i valori correnti
    UpDisplay=0;//Azzera il contatore
    
    //Verifica se deve azzerare il registro dei valori di picco
    EncoderAppo = (TestEncoder(0, NumINA219));
    
    if(EncoderAppo == 1)
    {
      for(uint8_t i=0; i<NumINA219; i++)
      {
        CurrentPeakValue[i]=0;
      }
    }
  }

//Cilo di misura
  if (Timer1Flag==1)
  {
    UpdateValue();
    UpDisplay++;
    Timer1Flag=0;
  }
  
}

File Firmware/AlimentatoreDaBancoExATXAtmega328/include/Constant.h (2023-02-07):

//===============================================================
//Costanti di sistema
//===============================================================
#define EEPromStartAddress 0x0000

#define RigheHelp 15

#define TMinCiclo 1000 //Microsecondi
#define CPS 400.0
#define FTaglio 1.0
//#define KFiltro (FTaglio/CPS)
#define KFiltro 0.05

#define DebugOn 9
//===============================================================
//Costanti INA219_33
//===============================================================

//3.3 volt 30A -> 
#define NumINA219 3
#define DefaultKConvCurrentCalibration 0.04096

#define INA219_Address33 0x40
#define KCorrectionV33 1.35// K
#define OffsetCurrentV33 60// K
#define Volt33 16// V
#define CurrentMAX33 30
#define CurrentLSB33 1// mA
#define RShunt33 0.00265// Ohm
#define VShunt33 80

#define INA219_Address5 0x41
#define KCorrectionV5 1.45// K
#define OffsetCurrentV5 80// K
#define Volt5 16// V
#define CurrentMAX5 30
#define CurrentLSB5 1// mA
#define RShunt5 0.00265// Ohm
#define VShunt5 80

#define INA219_Address12 0x42
#define KCorrectionV12 1.015// K
#define OffsetCurrentV12 140// K
#define Volt12 16// V
#define CurrentMAX12 22
#define CurrentLSB12 1// mA
#define RShunt12 0.00265// Ohm
#define VShunt12 80


//===============================================================
//Costanti LCD
//===============================================================

//Il valore assegnato alle costanti NON è il pin o il bit della porta ma
//è un valore simbolico il quale, posizionato nelle otto posizioni dopo 
//l'indirizzo, indica alla libreria il ruolo del bit
#define RS 4
#define RW 5
#define En 6

#define D4 11
#define D5 12
#define D6 13
#define D7 14

#define BackLite 16

#define COLUMS           16   //LCD columns
#define ROWS             2    //LCD rows
#define LCD_SPACE_SYMBOL 0x20 //space symbol from LCD ROM, see p.9 of GDM2004D datasheet

#define LCDWelcomeT1 " NutriMento ATX "
#define LCDWelcomeT2 "Firm.r2  Hard.r0"

#define LCDBackPlaneRow0 "+00.0V    00.00A000.0W   ^00.00A"
#define LCDBackPlaneRow1 "000.0W   ^00.00A"

#define LCDWelcomeDelay 5000

#define PacMan00 0x04
#define PacMan01 0x0A
#define PacMan02 0x11
#define PacMan03 0x11
#define PacMan04 0x17
#define PacMan05 0x11
#define PacMan06 0x11
#define PacMan07 0x0E

#define PacMan10 0x04
#define PacMan11 0x0A
#define PacMan12 0x11
#define PacMan13 0x13
#define PacMan14 0x14
#define PacMan15 0x13
#define PacMan16 0x11
#define PacMan17 0x0E

#define PacMan20 0x04
#define PacMan21 0x0A
#define PacMan22 0x13
#define PacMan23 0x14
#define PacMan24 0x18
#define PacMan25 0x14
#define PacMan26 0x13
#define PacMan27 0x0E

#define PacMan30 0x04
#define PacMan31 0x0A
#define PacMan32 0x11
#define PacMan33 0x11
#define PacMan34 0x1D
#define PacMan35 0x11
#define PacMan36 0x11
#define PacMan37 0x0E

#define PacMan40 0x04
#define PacMan41 0x0A
#define PacMan42 0x11
#define PacMan43 0x19
#define PacMan44 0x05
#define PacMan45 0x19
#define PacMan46 0x11
#define PacMan47 0x0E

#define PacMan50 0x04
#define PacMan51 0x0A
#define PacMan52 0x19
#define PacMan53 0x05
#define PacMan54 0x03
#define PacMan55 0x05
#define PacMan56 0x19
#define PacMan57 0x0E

#define UpArrow00 0x04
#define UpArrow01 0x0E
#define UpArrow02 0x15
#define UpArrow03 0x04
#define UpArrow04 0x04
#define UpArrow05 0x04
#define UpArrow06 0x04
#define UpArrow07 0x04

#define PacManDelay 250


//===============================================================
//Costanti Encoder
//===============================================================

#define PIN_IN1 2
#define PIN_IN2 3
#define EncoderSwitch 4

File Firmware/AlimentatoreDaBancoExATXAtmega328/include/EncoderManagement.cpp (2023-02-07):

//Gestisce l'encoder


/**Gestisce il funzionamento dell'encoder
 * definendo il range reso nella variabile EncoderPointer
 * (min -> valore minimo, Max -> valore massimo
 * In uscita rende lo stato del pulsante
*/
int TestEncoder(int min, int Max)
{
  int SwitchStatus = 0;
  
//  encoder.tick(); // just call tick() to check the state.
  encoder->tick(); // just call tick() to check the state.
  
//  EncoderPointer =+ encoder.getPosition();
  EncoderPointer =+ encoder->getPosition();
  if (EncoderPointer >= Max) 
  {
    EncoderPointer = min;
//    encoder.setPosition(EncoderPointer);
    encoder->setPosition(EncoderPointer);
  }
  if (EncoderPointer < min) 
  {
    EncoderPointer = Max;
   // encoder.setPosition(EncoderPointer);
    encoder->setPosition(EncoderPointer);
  }

  /**Controlla lo stato del pulsante dell'encoder e rimane
   * in attesa che venga rilasciato
  */ 
  while (digitalRead(EncoderSwitch)==0)
  {
    SwitchStatus=1;
  }
  if (digitalRead(DebugOn) == 0)
  {
    Serial.print("Encoder ");
    Serial.println(EncoderPointer);
  }

  return(SwitchStatus);
}

/**Inizializza l'encoder con il valore utile alla funzione che lo sta utilizzando
*/
void InitEncoder(int ThisPoint)
{
//  encoder.setPosition(ThisPoint);
  encoder->setPosition(EncoderPointer);
}

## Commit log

2023-02-13 Nuovi Aggiornamenti Box
    Nuovi elementi Box
    [AlimentatoreExPC-Pannello Laterale DX.stl, AlimentatoreExPC-Pannello Laterale SX.stl, AlimentatoreExPC-Placca Morsetti.stl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]
2023-02-13 PCB
    PCB e schemi
    [bom.csv, designators.csv, positions.csv]
2023-02-14 BOM e aggiornamenti vari
    [AlimentatoreDaBancoExATX-r01-BOM.xlsx]
2023-03-19 Stampa Crality10S Uggello da 1mm
    Aggiornamento file di stampa
